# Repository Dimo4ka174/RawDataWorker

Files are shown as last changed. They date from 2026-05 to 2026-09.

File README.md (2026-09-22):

# RawDataWorker

> Arduino-based current-transformer data collector that publishes machine
> "working / idle" state to the **AWM** monitoring system over HTTP.

[]()
[]()




---

## Overview

`RawDataWorker` is a small hardware agent that turns an ordinary
current transformer (CT) into a **non-invasive machine activity sensor**.
It measures the RMS current drawn by the machine's power line, decides
whether the machine is currently working or idle, and pushes the state
to the **AWM** backend via a plain HTTP `POST`.

The project is part of a larger monitoring stack:

```
┌──────────────┐   HTTP/JSON   ┌──────────────┐   SignalR   ┌────────────┐
│ RawDataWorker│ ────────────► │     AWM      │ ──────────► │  Dashboard │
│  (Arduino)   │               │  (ASP.NET)   │             │  (browser) │
└──────────────┘               └──────────────┘             └────────────┘
```

This repository contains **only the firmware and hardware artifacts**.
The backend lives in a separate repository.

---

## How it works

1. The current transformer is clamped onto one phase of the machine's
   power cable. It outputs a small AC voltage proportional to the line
   current.
2. The Arduino samples the CT via `EmonLib::calcIrms()` and computes
   the RMS current.
3. Estimated active power is `P ≈ U · I` (nominal 230 V).
4. A simple **debouncer** requires `N` consecutive equal readings before
   the state is considered stable.
5. When the stable state differs from the last state that was successfully
   sent, the Arduino opens a TCP connection to the AWM backend and issues:

   ```http
   POST /api/Wincc/updateMachineStatus HTTP/1.1
   Host: 192.168.10.200
   Content-Type: application/json
   Content-Length: 87
   Connection: close

   {"machineName":"Danobat","Condition":true,"current":3.42,"power":787}
   ```

6. The server replies `200 OK` with a body indicating whether the state
   was actually changed. The Arduino treats any `200 OK` as success.

---

## Hardware

| Component | Notes |
| --- | --- |
| Arduino Mega 2560 | Any AVR board with enough RAM will do |
| Ethernet Shield W5100 | Or a compatible W5100/W5500 module |
| SCT-013-030 CT | 30 A / 1 V output; adjust `CT_CALIBRATION` to taste  |
| Burden resistor | Already built into the SCT-013-030 |
| 3D-printed enclosure  | See [`hardware/case`](hardware/case) |

### Wiring

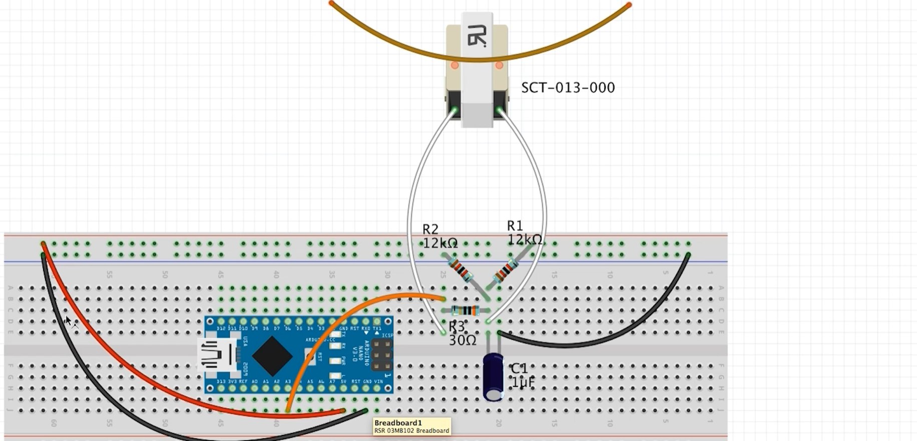
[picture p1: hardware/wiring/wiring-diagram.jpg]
Wiring


> ⚠️ The current transformer must be clamped **around a single phase
> conductor**, not around the whole cable. Otherwise the magnetic fields
> cancel out and you will read ~0 A.

Photos of the assembled device: [`hardware/photos`](hardware/photos).

---

## Firmware

### Dependencies

- [`EmonLib`](https://github.com/openenergymonitor/EmonLib) — current measurement
- `Ethernet` — W5100/W5500 networking
- `SPI` — bundled with the AVR core

### Build & flash

1. Open `firmware/RawDataWorker/RawDataWorker.ino` in the Arduino IDE.
2. Select **Tools → Board → Arduino Mega or Mega 2560**.
3. Select the correct serial port.
4. Adjust the configuration block at the top of the sketch
   (IP addresses, `MACHINE_NAME`, `CT_CALIBRATION`, …).
5. Upload and open the Serial Monitor at **9600 baud**.

### Configuration

All tunables live in a single block at the top of the sketch:

| Constant | Purpose |
| --- | --- |
| `mac`, `localIp`, … | Static network configuration of the Arduino |
| `serverIp`, `serverPort` | AWM backend address |
| `MACHINE_NAME` | Identifier sent in every payload |
| `CT_CALIBRATION` | EmonLib calibration coefficient; tune to your CT |
| `CURRENT_THRESHOLD_A` | Current above which the machine is considered active |
| `MAINS_VOLTAGE_V` | Nominal voltage used for the power estimate |
| `NEED_STABLE_READINGS` | Number of equal readings to confirm a state change |
| `MEASURE_INTERVAL_MS` | Sampling period |
| `HTTP_TIMEOUT_MS` | Socket timeout for the outgoing request |

### Serial output example

```
========================================
===     RAW DATA WORKER (current)    ===
========================================
Sensor... OK
Ethernet... OK, IP=192.168.10.177
Server: 192.168.10.200:5050
========================================
0.02 A | Stop 1/3
0.02 A | Stop 2/3
0.01 A | Stop 3/3
3.41 A | Work 1/3
3.44 A | Work 2/3
3.39 A | Work 3/3 -> sending... [CHANGED] OK
```

---

## Protocol

See [`docs/protocol.md`](docs/protocol.md) for the full request/response
contract, error handling and retry behaviour.

---

## Pre-built firmware

If you just want to flash a working binary without setting up the
Arduino toolchain, grab `RawDataWorker.ino.standard.hex` from the
[latest release](https://github.com/Dimo4ka174/RawDataWorker/releases/latest).

The pre-built binary uses the default configuration from the source
code. If you need a different IP address, machine name, or CT
calibration, build the sketch yourself using the instructions above.

---

## Design notes & known limitations

- **Blocking HTTP.** While the request is in flight (up to
  `HTTP_TIMEOUT_MS`), the loop does not sample. At a 1 Hz rate this is
  acceptable; if higher frequencies are needed, the HTTP client should
  be rewritten as a non-blocking state machine.
- **`P ≈ U · I`.** This is an *apparent* power estimate. For machines
  with poor power factor the real active power may be lower. A true
  energy meter or a PZEM-004T module would give real power directly.
- **EmonLib is in maintenance mode.** A future revision may switch to
  `EmonLibCM` or `EmonLibDB` for continuous, interrupt-driven sampling.
- **No TLS.** The device talks plain HTTP on a trusted industrial LAN.

---

## Repository layout

```
.
├── .github/workflows/    CI: build the sketch on every push
├── firmware/
│   └── RawDataWorker/    Arduino sketch (folder name = sketch name)
├── hardware/
│   ├── case/             3D enclosure drawings
│   ├── photos/           Photos of the assembled device
│   └── wiring/           Wiring diagram
├── docs/
│   └── protocol.md       HTTP contract between the device and AWM
├── .editorconfig
├── .gitattributes
├── .gitignore
├── LICENSE
└── README.md
```

> The `firmware/RawDataWorker/` folder has the same name as the `.ino`
> file inside it. This is required by the Arduino build system — the
> sketch name must match the folder name.

---

## License

MIT — see [LICENSE](LICENSE).

Hardware artifacts (drawings, enclosure) are released under the same
license unless stated otherwise.

---

## Author

**Dmitry Kharchenko** — C#/.NET backend developer with a soft spot for
the hardware side of things.

- GitHub: [@Dimo4ka174](https://github.com/Dimo4ka174)
- Email: `Dmitry.Kharchenko.Dev@yandex.ru`

> This repository is a personal project. It does not contain any code,
> schematics, or data belonging to previous or current employers.

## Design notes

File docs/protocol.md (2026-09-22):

# HTTP Protocol — RawDataWorker ↔ AWM

This document describes the wire contract between the Arduino firmware
(`RawDataWorker`) and the AWM backend.

- **Transport:** plain HTTP/1.1 over TCP
- **Direction:** Arduino → AWM (one-way from the client's perspective)
- **Default endpoint:** `POST /api/Wincc/updateMachineStatus`
- **Content type:** `application/json`
- **Encoding:** UTF-8, no BOM

> ⚠️ There is no TLS and no authentication. The device is expected to run
> on an isolated industrial LAN. If you expose the endpoint to a broader
> network, put it behind a reverse proxy with authentication.

---

## 1. Endpoint

### `POST /api/Wincc/updateMachineStatus`

Called by the Arduino whenever the debounced machine state differs from
the last state that was successfully delivered.

#### Request headers

| Header | Value | Notes |
| --- | --- | --- |
| `Host` | `<server-ip>` | Plain IP, no DNS |
| `Content-Type` | `application/json` | |
| `Content-Length` | `<n>` | Length of the JSON body |
| `Connection` | `close` | One request per TCP connection |

#### Request body

```json
{
  "machineName": "Danobat",
  "Condition": true,
  "current": 3.42,
  "power": 787
}
```

| Field | Type | Units | Description |
| --- | --- | ----- | --- |
| `machineName` | string  | — | Logical machine identifier known by AWM |
| `Condition` | boolean | — | `true` = working, `false` = idle |
| `current` | number  | A | RMS current, two decimals |
| `power` | number  | W | Estimated apparent power `U · I`, integer |

`Condition` is capitalised to match the existing AWM DTO
(`DemoStatusDto.Condition`). The other fields are lower-case for
historical reasons; the backend treats them case-insensitively.

#### Response

`AWM` returns `200 OK` for every successfully parsed request. The
response body carries a hint about whether the state actually changed:

```json
{ "changed": true }
```

| Body | Meaning |
| --- | --- |
| `{"changed":true}` | Server accepted the update and the state changed |
| `{"changed":false}` | Server accepted the update, but the state was same |
| *(anything else)* + 200  | Accepted; firmware treats it as success |

The Arduino considers the delivery successful if **either**:

- the HTTP status line contains `200 OK`, **or**
- the body contains `"changed":true` / `"changed":false`.

Any other outcome (timeout, connection refused, non-200 response) is
treated as a failure and logged to the serial console. The firmware does
**not** retry on its own — instead it waits for the next state change and
sends again.

---

## 2. Timing

| Parameter | Value | Source |
| --- | --- | --- |
| Sampling period | 1000 ms | `MEASURE_INTERVAL_MS` |
| Debounce window | 3 samples  | `NEED_STABLE_READINGS` |
| HTTP socket timeout | 2000 ms | `HTTP_TIMEOUT_MS` |
| Effective worst-case latency | ~5 s | measure + debounce + timeout |

While the HTTP request is in flight, the sampling loop is paused. At a
1 Hz cadence this is acceptable. If a higher sampling rate is ever
required, the HTTP layer must be reworked into a non-blocking state
machine.

---

## 3. Example exchange

Full request as it appears on the wire (`\r\n` shown explicitly):

```
POST /api/Wincc/updateMachineStatus HTTP/1.1\r\n
Host: 192.168.10.200\r\n
Content-Type: application/json\r\n
Content-Length: 87\r\n
Connection: close\r\n
\r\n
{"machineName":"Danobat","Condition":true,"current":3.42,"power":787}
```

Typical response:

```
HTTP/1.1 200 OK\r\n
Content-Type: application/json\r\n
Content-Length: 18\r\n
Connection: close\r\n
\r\n
{"changed":true}
```

---

## 4. Error handling

| Scenario | Firmware behaviour |
| --- | --- |
| `connect()` fails | Log `ERR: connect failed`, skip cycle |
| TCP connects, no response in 2 s  | Log `ERR: no 200 OK`, close socket, skip cycle |
| Response is not `200 OK` | Same as above |
| Response is `200 OK` | Log `[CHANGED]` or `[UNCHANGED]`, update state |
| Ethernet cable unplugged | `Ethernet.localIP() == 0.0.0.0` at boot → halt |

There is no exponential backoff and no persistent retry queue. The
device only reports state *changes*, so a missed delivery will be
retried on the next change anyway. This is a deliberate design choice to
keep the firmware small and predictable.

---

## 5. Versioning

The protocol is not versioned. Any change to the JSON shape requires
updating the firmware and the backend DTO together. For a system of
this size, adding a `version` field would be over-engineering.

---

## 6. Reference implementation

- Firmware: [`firmware/RawDataWorker/RawDataWorker.ino`](../firmware/RawDataWorker/RawDataWorker.ino)
- Backend: `AWM/Controllers/WinccController` (private repository)

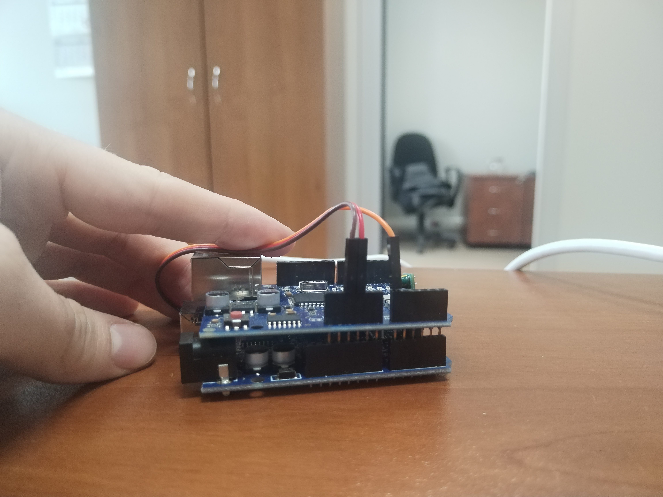
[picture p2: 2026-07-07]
hardware/photos/side-view.jpg

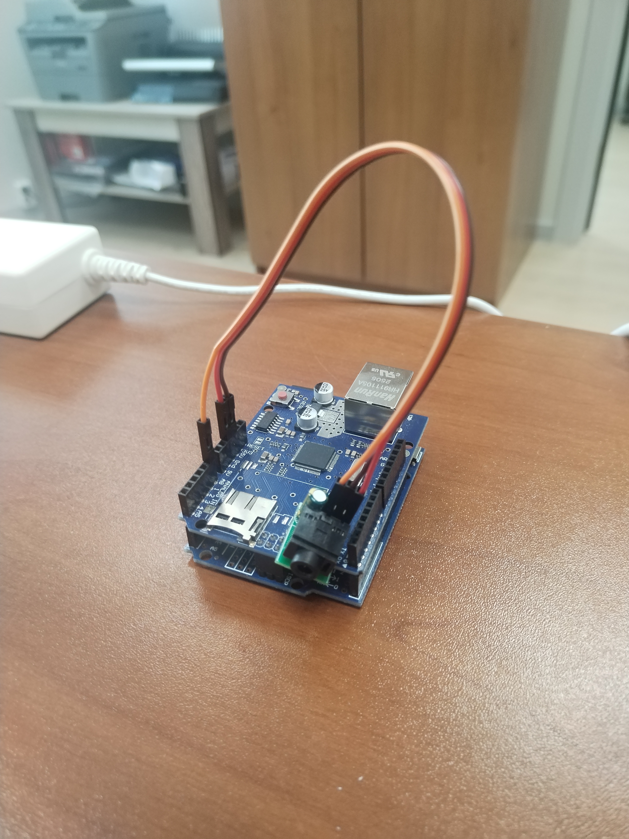
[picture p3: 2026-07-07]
hardware/photos/rear-view.jpg

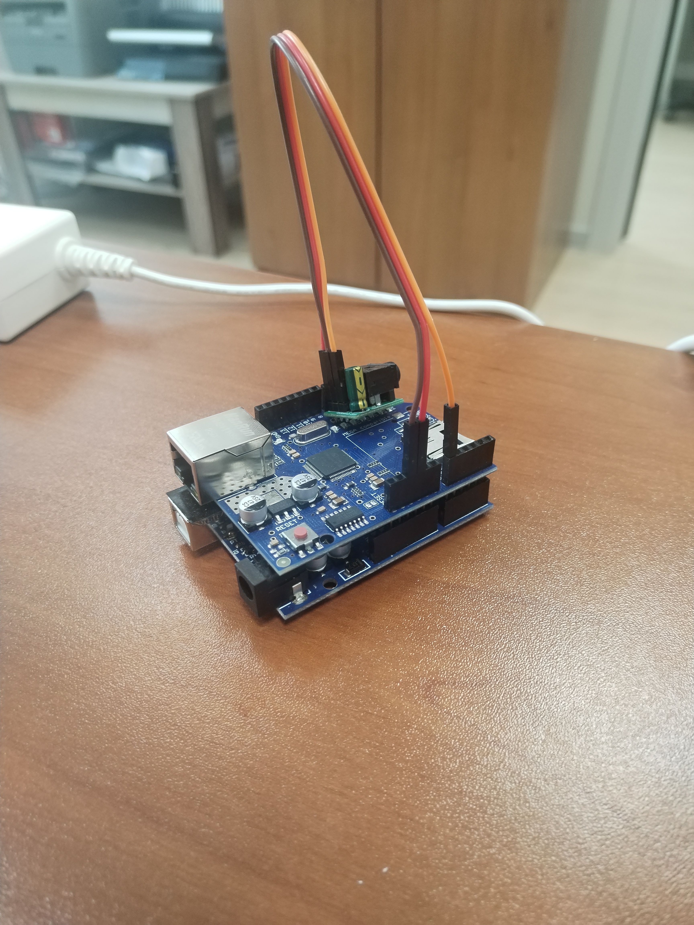
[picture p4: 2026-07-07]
hardware/photos/top-view.jpg

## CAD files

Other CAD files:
hardware/case/case.dwg

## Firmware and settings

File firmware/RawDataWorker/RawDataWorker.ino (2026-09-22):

// RawDataWorker — Arduino current-transformer data collector.
// Publishes machine state (working / idle) to AWM over HTTP.
//
// Board:   Arduino Mega 2560 + Ethernet Shield (W5100)
// Sensor:  SCT-013 current transformer on analog pin A0
// Library: EmonLib

#include <SPI.h>
#include <Ethernet.h>
#include <EmonLib.h>
#include <avr/wdt.h>

// ============================ CONFIG ============================

// --- Network ---
byte mac[] = { 0xDE, 0xAD, 0xBE, 0xEF, 0xFE, 0xED };
IPAddress localIp(192, 168, 10, 177);
IPAddress gateway(192, 168, 10, 1);
IPAddress subnet(255, 255, 255, 0);
IPAddress dns(8, 8, 8, 8);

IPAddress serverIp(192, 168, 10, 200);
const int   serverPort = 5050;
const char* SERVER_ENDPOINT = "/api/Wincc/updateMachineStatus";

// --- Machine identity ---
const char* MACHINE_NAME = "Danobat";

// --- Current transformer ---
const uint8_t CT_ANALOG_PIN  = 0;
const float   CT_CALIBRATION = 4.0f;    // EmonLib calibration coefficient
const int     IRMS_SAMPLES   = 1480;    // Samples per measurement

// --- Thresholds ---
const float MAINS_VOLTAGE_V      = 230.0f; // Nominal voltage for P ≈ U·I
const float CURRENT_THRESHOLD_A  = 0.05f;  // Above → "working"

// --- Timing ---
const unsigned long MEASURE_INTERVAL_MS = 1000;
const unsigned long HTTP_TIMEOUT_MS     = 2000;
const int           NEED_STABLE_READINGS = 3;

// ============================ STATE ============================

EthernetClient client;
EnergyMonitor  emon;

int  stableCount      = 0;
bool lastStableStatus = false;
bool lastSentStatus   = false;
unsigned long lastMeasureTime = 0;

// ============================ HTTP =============================

// Returns true if server replied 200 OK.
bool sendStatus(bool isWorking, float current, float power) {
  char body[160];
  int bodyLen = snprintf(
      body, sizeof(body),
      "{\"machineName\":\"%s\",\"Condition\":%s,\"current\":%.2f,\"power\":%.0f}",
      MACHINE_NAME,
      isWorking ? "true" : "false",
      current, power);

  if (bodyLen <= 0 || bodyLen >= (int)sizeof(body)) {
    Serial.println(F("ERR: payload overflow"));
    return false;
  }

  if (!client.connect(serverIp, serverPort)) {
    Serial.println(F("ERR: connect failed"));
    return false;
  }

  client.print(F("POST "));
  client.print(SERVER_ENDPOINT);
  client.print(F(" HTTP/1.1\r\nHost: "));
  client.print(serverIp);
  client.print(F("\r\nContent-Type: application/json\r\nContent-Length: "));
  client.print(bodyLen);
  client.print(F("\r\nConnection: close\r\n\r\n"));
  client.write((const uint8_t*)body, bodyLen);

  unsigned long deadline = millis() + HTTP_TIMEOUT_MS;
  bool httpOk   = false;
  bool changed  = false;
  char line[128];
  size_t pos = 0;

  while (millis() < deadline) {
    while (client.available()) {
      char c = client.read();
      if (c == '\n') {
        line[pos] = '\0';
        if (strstr(line, "200 OK"))            httpOk  = true;
        if (strstr(line, "\"changed\":true"))  changed = true;
        pos = 0;
      } else if (c != '\r' && pos < sizeof(line) - 1) {
        line[pos++] = c;
      }
    }
    if (!client.connected() && !client.available()) break;
  }

  client.stop();

  if (!httpOk) {
    Serial.println(F("ERR: no 200 OK"));
    return false;
  }
  Serial.print(changed ? F(" [CHANGED]") : F(" [UNCHANGED]"));
  return true;
}

// ============================ SETUP ============================

void setup() {
  wdt_disable();          // avoid reset loop during init
  Serial.begin(9600);
  delay(1000);

  Serial.println(F("========================================"));
  Serial.println(F("===     RAW DATA WORKER (current)    ==="));
  Serial.println(F("========================================"));

  Serial.print(F("Sensor... "));
  emon.current(CT_ANALOG_PIN, CT_CALIBRATION);
  Serial.println(F("OK"));

  Serial.print(F("Ethernet... "));
  Ethernet.begin(mac, localIp, dns, gateway, subnet);
  delay(1500);

  if (Ethernet.localIP() == IPAddress(0, 0, 0, 0)) {
    Serial.println(F("ERROR"));
    while (true) { delay(1000); }
  }
  Serial.print(F("OK, IP="));
  Serial.println(Ethernet.localIP());
  Serial.print(F("Server: "));
  Serial.print(serverIp);
  Serial.print(':');
  Serial.println(serverPort);
  Serial.println(F("========================================"));

  lastMeasureTime = millis();
  wdt_enable(WDTO_8S);
}

// ============================ LOOP =============================

void loop() {
  wdt_reset();
  unsigned long now = millis();

  if (now - lastMeasureTime < MEASURE_INTERVAL_MS) {
    delay(10);
    return;
  }
  lastMeasureTime = now;

  float current  = emon.calcIrms(IRMS_SAMPLES);
  float power    = current * MAINS_VOLTAGE_V;
  bool  isActive = (current > CURRENT_THRESHOLD_A);

  Serial.print(current, 2);
  Serial.print(F(" A | "));
  Serial.print(isActive ? F("Work") : F("Stop"));

  if (isActive == lastStableStatus) {
    stableCount++;

    int shown = stableCount > NEED_STABLE_READINGS
                    ? NEED_STABLE_READINGS
                    : stableCount;
    Serial.print(' ');
    Serial.print(shown);
    Serial.print('/');
    Serial.print(NEED_STABLE_READINGS);

    if (stableCount == NEED_STABLE_READINGS && isActive != lastSentStatus) {
      Serial.print(F(" -> sending..."));
      if (sendStatus(isActive, current, power)) {
        Serial.print(F(" OK"));
        lastSentStatus = isActive;
      } else {
        Serial.print(F(" FAIL"));
      }
    }
  } else {
    stableCount = 0;
    lastStableStatus = isActive;
    Serial.print(F(" (reset)"));
  }

  Serial.println();
}

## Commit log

2026-05-20 Вынес код по работе с ТТ в репозиторий
    Код адаптирован для работает для переменного тока с напряжением 220-230V, мертвая зона срабатывания по силе тока 0,05A.
    Все стандартные настройки для работы с сервером нужно исправлять в первых 20ти строках файла
    В репозиторий также приложил чертежи платы
    [ArduinoBoard.dwg]
2026-05-22 Корректировка значений с новой платой
2026-05-22 Добавил в схему новую плату для передачи показаний с сенсора
    [ArduinoBoard.dwg]
2026-07-07 Фотографии
2026-09-22 Add CI workflow and protocol documentation
    [case.dwg]
